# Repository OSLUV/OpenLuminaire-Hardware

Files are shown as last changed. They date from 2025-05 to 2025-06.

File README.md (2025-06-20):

# OpenLuminaire-Hardware
Electrical and mechanical files for OSLUV Luminaire - an [OSHWA certified](https://certification.oshwa.org/us002747.html) Open Source 222nm luminiare.

certification-mark-US002747-stacked

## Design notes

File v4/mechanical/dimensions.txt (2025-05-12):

"emitting_window_width"=63mm
"emitting_window_height"=48mm
"emitter_mounting_peg_diameter"=3.4mm
"emitter_wall_clearance"=0.5mm
"wall_thickness"=2mm
"ballast_pcb_length"=88.9mm
"ballast_pcb_width"=88.9mm
"ballast_pcb_clearance"=0.3mm
"emitter_balast_separation"=8mm
"emitter_ballast_spacer_clearance"=0.2mm
"edge_radius"=5mm
"grille_slot_width"=2mm
"grille_slot_length"=3.5mm
"grille_spacing"=6.3mm
"button_hole_diameter"=3.5mm
"hoop_inside_width"=75.9mm
"hoop_inside_height"=65mm
"hoop_inner_outer_clearance"=0.05mm

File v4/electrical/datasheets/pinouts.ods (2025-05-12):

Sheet: TPS54202_buck
Pin Number | Pin Name | Electrical Type | Group | Description
1 | GND | Power |  | Ground pin. Source terminal of low-side power NFET as well as the ground terminal for controller circuit. Connect sensitive VFB to this GND at a single point.
2 | SW | Power |  | Switch node connection between high-side NFET and low-side NFET.
3 | VIN | Power |  | Input voltage supply pin. The drain terminal of high-side power NFET
4 | FB | Input |  | Converter feedback input. Connect to output voltage with feedback resistor divider.
5 | EN | Input |  | This pin is the enable pin. Float the EN pin to enable.
6 | BOOT | Power |  | Supply input for the high-side NFET gate drive circuit. Connect a 0.1-μF capacitor between BOOT and SW pins.
Undervoltage Lockout
 |  | VSTART (V) | VSTOP (V) | VENfalling (V) | VENrising (V) | Ip (μA) | Ih (μA)
 |  | 22.2 | 20.185 | 1.19 | 1.22 | 0.7 | 1.55
R4 (Ω) | R5 (Ω)
937395.397489541 | 52856.9532713037
R4 Rounded (kΩ) | R5 Rounded (kΩ)
937 | 52.9

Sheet: Sheet2
Number | Name | Type | Description
1 | Vdd_IO | Power | Power supply for I/O pins
2 | NC | NC | Not connected
3 | NC | NC | Not connected
4 | SCL/SPC | Input | Clock
5 | GND | Power | 0V supply
6 | SDA/SDI/SDO | I/O | I2C Serial data/SPI data in/3-wire data out
7 | SDO/SA0 | I/O | SPI serial data output (SDO)/I2C address LSB
8 | CS | Input | Low: SPI enabled/ High: I2C enabled
9 | INT2 | Output | Inertial interrupt 2
10 | RES | Input | Connect to GND
11 | INT1 | Output | Inertial interrupt 1
12 | GND | Power | 0V supply
13 | ADC3 | Input | Analog-to-digital converter input 3
14 | Vdd | Power | Power supply
15 | ADC2 | Input | Analog-to-digital converter input 2
16 | ADC1 | Input | Analog-to-digital converter input 1

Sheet: STUSB4500_USB_PD
Pin Number | Pin Name | Electrical Type | Group | Description | Typical Connection
1 | CC1DB | Input |  | Dead battery enable on CC1 pin | To CC1 pin if used or ground
2 | CC1 | I/O |  | Type-C configuration channel 1 | To Type-C receptacle A5
3 | NC | Passive |  | Not Connected | Floating
4 | CC2 | I/O |  | Type-C configuration channel 2 | To Type-C receptacle B5
5 | CC2DB | I/O |  | Dead battery enable on CC2 pin | To CC2 pin if used or ground
6 | RESET | Input |  | Reset input, active high | From system
7 | SCL | I/O | I2C | I2C clock input | To I²C master, ext. pull-up
8 | SDA | I/O | I2C | I2C data input/output, active low open drain | To I²C master, ext. pull-up
9 | DISCH | I/O |  | Internal discharge path or external discharge path enable, active low open drain | From power system (internal path) or to the discharge path switch (external path), ext. pull- up
10 | GND | Power | Power | Ground | Ground
11 | ATTACH | Open Collector | Status | Attachment detection, active low open drain | To MCU if any, ext. pull-up
12 | ADDR0 | Input | I2C | I²C device address setting | Static, to ground or ext. pull-up for address selection, to ground if no connection to MCU
13 | ADDR1 | Input | I2C | I²C device address setting | Static, to ground or ext. pull-up for address selection, to ground if no connection to MCU
14 | POWER_OK3 | Open Collector | Status | Power contract flag, active low open drain | To power system, ext. pull-up
15 | GPIO | Open Collector | Status | General purpose output, active low open drain | To system, ext. pull-up
16 | VBUS_EN_SNK | Open Collector | Status | VBUS sink power path enable, active low open drain | To power switch or to power system, ext. pull-up
17 | A_B_SIDE | Open Collector | Status | Cable orientation, active low open drain | USB super speed MUX select, ext. pull-up
18 | VBUS_VS_DISCH | Input |  | VBUS voltage monitoring and discharge path | From VBUS, receptacle side
19 | ALERT | Open Collector | I2C | I2C interrupt, active low open drain | To I²C master, ext. pull-up
20 | POWER_OK2 | Open Collector | Status | Power contract flag, active low open drain | To power switch or to power system, ext. pull-up
21 | VREG_1V2 | Power | Power | 1.2 V internal regulator output | 1 µF typ. decoupling capacitor
22 | VSYS | Power | Power | Power supply from system | From power system, connect to ground if not used
23 | VREG_2V7 | Power | Power | 2.7 V internal regulator output | 1 µF typ. decoupling capacitor
24 | VDD | Power | Power | Power supply from USB power line | From VBUS, receptacle side
PAD | GND | Power | Power | Exposed pad is connected to ground | To ground

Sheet: TPS55340_Boost
Pin Number | Pin Name | Electrical Type | Group | Description
1 | SW | Power |  | SW is the drain of the internal power MOSFET. Connect SW to the switched side of the boost or SEPIC inductor or the flyback transformer.
2 | VIN | Power |  | The input supply pin to the IC. Connect VIN to a supply voltage between 2.9 V and 32 V. It is acceptable for the voltage on the pin to be different from the boost power stage input.
3 | EN | Input |  | Enable pin. When the voltage of this pin falls below the enable threshold for more than 1 ms, the IC turns off.
4 | SS | Input |  | Soft-start programming pin. A capacitor between the SS pin and AGND pin programs soft-start timing.
5 | SYNC | Input |  | Switching frequency synchronization pin. An external clock signal can be used to set the switching frequency between 200 kHz and 1.0 MHz. If not used, this pin should be tied to AGND.
6 | AGND | Power |  | Signal ground of the IC
7 | COMP | Output |  | Output of the transconductance error amplifier. An external RC network connected to this pin compensates the regulator feedback loop.
8 | FB | Input |  | Error amplifier input and feedback pin for positive voltage regulation. Connect to the center tap of a resistor divider to program the output voltage.
9 | FREQ | Input |  | Switching frequency program pin. An external resistor connected between the FREQ pin and AGND sets the switching frequency.
10 | NC | Power |  | Reserved pin that must be connected to ground
11 | PGND | Power |  | Power ground of the IC. It is connected to the source of the internal power MOSFET switch.
12 | PGND | Power |  | Power ground of the IC. It is connected to the source of the internal power MOSFET switch.
13 | PGND | Power |  | Power ground of the IC. It is connected to the source of the internal power MOSFET switch.
14 | NC | Power |  | Reserved pin that must be connected to ground
15 | SW | Power |  | SW is the drain of the internal power MOSFET. Connect SW to the switched side of the boost or SEPIC inductor or the flyback transformer.
16 | SW | Power |  | SW is the drain of the internal power MOSFET. Connect SW to the switched side of the boost or SEPIC inductor or the flyback transformer.
PAD | PowerPAD | Power |  | The PowerPAD should be soldered to the AGND. If possible, use thermal vias to connect to internal ground plane for improved power dissipation.

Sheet: ESP32-C3-WROOM-02-N4
Pin Number | Pin Name | Electrical Type | Group | Description
1 | 3V3 | Power | Power | Power supply
2 | EN | Input |  | High: on, enables the chip. Low: off, the chip powers off. Note: Do not leave the EN pin floating.
3 | GPIO4/ADC1_CH4/FSPIHD/MTMS | I/O | SPI | GPIO4, ADC1_CH4, FSPIHD, MTMS
4 | GPIO5/ADC2_CH0/FSPIWP/MTDI | I/O | SPI | GPIO5, ADC2_CH0, FSPIWP, MTDI
5 | GPIO6/FSPICLK/MTCK | I/O | SPI | GPIO6, FSPICLK, MTCK
6 | GPIO7/FSPID/MTDO | I/O | SPI | GPIO7, FSPID, MTDO
7 | GPIO8 | I/O | GPIO | GPIO8
8 | GPIO9 | I/O | GPIO | GPIO9
9 | GND | Power | Power | Ground
10 | GPIO10/FSPICS0 | I/O | GPIO | GPIO10, FSPICS0
11 | GPIO20/U0RXD | I/O | GPIO | GPIO20, U0RXD
12 | GPIO21/U0TXD | I/O | GPIO | GPIO21, U0TXD
13 | GPIO18/USB_D- | I/O | GPIO | GPIO18, USB_D-
14 | GPIO19/USB_D+ | I/O | GPIO | GPIO19, USB_D+
15 | GPIO3/ADC1_CH3 | I/O | GPIO | GPIO3, ADC1_CH3
16 | GPIO2/ADC1_CH2/FSPIQ | I/O | GPIO | GPIO2, ADC1_CH2, FSPIQ
17 | GPIO1/ADC1_CH1/XTAL_32K_N | I/O | GPIO | GPIO1, ADC1_CH1, XTAL_32K_N
18 | GPIO0/ADC1_CH0/XTAL_32K_P | I/O | GPIO | GPIO0, ADC1_CH0, XTAL_32K_P
19 | GND | Power | Power | Ground

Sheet: ESP32-C6-MINI-1-N4
Pin Number | Pin Name | Electrical Type | Group | Description | Function Names
1 | GND | Power | Power | Ground | GND
2 | GND | Power | Power | Ground | GND
3 | 3V3 | Power | Power | Power supply | 3V3
4 | NC | Passive | NC | NC | NC
5 | IO2 | I/O | GPIO | GPIO2, LP_GPIO2, LP_UART_RTSN, ADC1_CH2, FSPIQ | GPIO2/LP_GPIO2/LP_UART_RTSN/ADC1_CH2/FSPIQ
6 | IO3 | I/O | GPIO | GPIO3, LP_GPIO3, LP_UART_CTSN, ADC1_CH3 | GPIO3/LP_GPIO3/LP_UART_CTSN/ADC1_CH3
7 | NC | Passive | NC | NC | NC
8 | EN | Input |  | High: on, enables the chip. Low: off, the chip powers off. Note: Do not leave the EN pin floating. | EN
9 | IO4 | I/O | GPIO | MTMS, GPIO4, LP_GPIO4, LP_UART_RXD, ADC1_CH4, FSPIHD | MTMS/GPIO4/LP_GPIO4/LP_UART_RXD/ADC1_CH4/FSPIHD
10 | IO5 | I/O | GPIO | MTDI, GPIO5, LP_GPIO5, LP_UART_TXD, ADC1_CH5, FSPIWP | MTDI/GPIO5/LP_GPIO5/LP_UART_TXD/ADC1_CH5/FSPIWP
11 | GND | Power | Power | Ground | GND
12 | IO0 | I/O | GPIO | GPIO0, XTAL_32K_P, LP_GPIO0, LP_UART_DTRN, ADC1_CH0 | GPIO0/XTAL_32K_P/LP_GPIO0/LP_UART_DTRN/ADC1_CH0
13 | IO1 | I/O | GPIO | GPIO1, XTAL_32K_N, LP_GPIO1, LP_UART_DSRN, ADC1_CH1 | GPIO1/XTAL_32K_N/LP_GPIO1/LP_UART_DSRN/ADC1_CH1
14 | GND | Power | Power | Ground | GND
15 | IO6 | I/O | GPIO | MTCK, GPIO6, LP_GPIO6, LP_I2C_SDA, ADC1_CH6, FSPICLK | MTCK/GPIO6/LP_GPIO6/LP_I2C_SDA/ADC1_CH6/FSPICLK
16 | IO7 | I/O | GPIO | MTDO, GPIO7, LP_GPIO7, LP_I2C_SCL, FSPID | MTDO/GPIO7/LP_GPIO7/LP_I2C_SCL/FSPID
17 | IO12 | I/O | GPIO | GPIO12, USB_D- | GPIO12/USB_D-
18 | IO13 | I/O | GPIO | GPIO13, USB_D+ | GPIO13/USB_D+
19 | IO14 | I/O | GPIO | GPIO14 | GPIO14
20 | IO15 | I/O | GPIO | GPIO15 | GPIO15
21 | NC | Passive | NC | NC | NC
22 | IO8 | I/O | GPIO | GPIO8 | GPIO8
23 | IO9 | I/O | GPIO | GPIO9 | GPIO9
24 | IO18 | I/O | GPIO | GPIO18, SDIO_CMD, FSPICS2 | GPIO18/SDIO_CMD/FSPICS2
25 | IO19 | I/O | GPIO | GPIO19, SDIO_CLK, FSPICS3 | GPIO19/SDIO_CLK/FSPICS3
26 | IO20 | I/O | GPIO | GPIO20, SDIO_DATA0, FSPICS4 | GPIO20/SDIO_DATA0/FSPICS4
27 | IO21 | I/O | GPIO | GPIO21, SDIO_DATA1, FSPICS5 | GPIO21/SDIO_DATA1/FSPICS5
28 | IO22 | I/O | GPIO | GPIO22, SDIO_DATA2 | GPIO22/SDIO_DATA2
29 | IO23 | I/O | GPIO | GPIO23, SDIO_DATA3 | GPIO23/SDIO_DATA3
30 | RXD0 | I/O | GPIO | U0RXD, GPIO17, FSPICS1 | U0RXD/GPIO17/FSPICS1
31 | TXD0 | I/O | GPIO | U0TXD, GPIO16, FSPICS0 | U0TXD/GPIO16/FSPICS0
32 | NC | Passive | NC | NC | NC
33 | NC | Passive | NC | NC | NC
34 | NC | Passive | NC | NC | NC
35 | NC | Passive | NC | NC | NC
36 | GND | Power | Power | Ground | GND
37 | GND | Power | Power | Ground | GND
38 | GND | Power | Power | Ground | GND
39 | GND | Power | Power | Ground | GND
40 | GND | Power | Power | Ground | GND
41 | GND | Power | Power | Ground | GND
42 | GND | Power | Power | Ground | GND
43 | GND | Power | Power | Ground | GND
44 | GND | Power | Power | Ground | GND
45 | GND | Power | Power | Ground | GND
46 | GND | Power | Power | Ground | GND
47 | GND | Power | Power | Ground | GND
48 | GND | Power | Power | Ground | GND
49 | GND | Power | Power | Ground | GND
50 | GND | Power | Power | Ground | GND
51 | GND | Power | Power | Ground | GND
52 | GND | Power | Power | Ground | GND
53 | GND | Power | Power | Ground | GND

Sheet: TMAG5273_Hall
Pin Number | Pin Name | Electrical Type | Group | Description
1 | SCL | I/O | Data | Serial clock.
2 | GND | Power | Power | Ground
3 | GND_(TEST) | Input | Data | TI Test Pin. Connect to ground in application.
4 | VCC | Power | Power | Power supply (1.7V - 3.6V)
5 | \INT | I/O | Data | Interrupt input/ output. If not used and connected to ground, set MASK_INTB = 1b.
6 | SDA | I/O | Data | Serial data.

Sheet: ushio_pxz120i3_ballast_dimming
Dimming on Pin 3
Minimum Voltage (V) | Target Voltage (V) | Maximum Voltage (V) | Power Level (%) | Theoretical PWM Duty Cycle (%)
0 | 0 | 1 | 100 | 0
1 | 1.5 | 2 | 70 | 45
2 | 2.5 | 3 | 40 | 75
3 | 3.5 | 4 | 20 | 100

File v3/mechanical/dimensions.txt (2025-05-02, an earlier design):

"emitting_window_width"=63mm
"emitting_window_height"=48mm
"emitter_mounting_peg_diameter"=3.4mm
"wall_thickness"=2mm
"ballast_pcb_length"=88.9mm
"ballast_pcb_width"=88.9mm
"emitter_balast_separation"=5mm
"emitter_wall_clearance"=0.5mm
"ballast_pcb_clearance"=0.3mm
"emitter_ballast_spacer_clearance"=0.2mm

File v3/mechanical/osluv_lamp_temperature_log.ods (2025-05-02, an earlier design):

Fan disabled, 2024-03-18
Heatsink Temperature (°C) | Transformer Temperature (°C) | Time
25.5 | 25.6 | 17:21:00
25.5 | 25.5 | 17:21:01
25.5 | 25.5 | 17:21:01
25.5 | 25.5 | 17:21:02
25.5 | 25.5 | 17:21:02
25.5 | 25.5 | 17:21:03
25.5 | 25.5 | 17:21:04
25.5 | 25.5 | 17:21:04
25.5 | 25.5 | 17:21:05
25.5 | 25.5 | 17:21:05
25.5 | 25.5 | 17:21:06
25.5 | 25.5 | 17:21:07
25.5 | 25.6 | 17:21:07
25.3 | 30.7 | 17:21:08
25.3 | 31.2 | 17:21:08
25.3 | 31.5 | 17:21:09
25.3 | 31.8 | 17:21:10
25.4 | 31.9 | 17:21:10
25.4 | 32.1 | 17:21:11
25.4 | 32.2 | 17:21:12
25.4 | 32.3 | 17:21:12
25.4 | 32.4 | 17:21:13
25.4 | 32.4 | 17:21:13
25.4 | 32.7 | 17:21:14
25.4 | 32.8 | 17:21:15
25.4 | 32.9 | 17:21:15
25.5 | 33.0 | 17:21:16
25.5 | 33.1 | 17:21:16
25.5 | 33.1 | 17:21:17
25.6 | 33.2 | 17:21:18
25.6 | 33.2 | 17:21:18
25.6 | 33.3 | 17:21:19
25.7 | 33.2 | 17:21:19
25.7 | 33.2 | 17:21:20
25.8 | 33.1 | 17:21:21
25.8 | 33.0 | 17:21:21
25.9 | 32.9 | 17:21:22
26.0 | 32.8 | 17:21:22
26.0 | 32.7 | 17:21:23
26.1 | 32.7 | 17:21:24
26.1 | 32.6 | 17:21:24
26.2 | 32.5 | 17:21:25
26.2 | 32.5 | 17:21:25
26.3 | 32.5 | 17:21:26
26.3 | 32.6 | 17:21:27
26.4 | 32.6 | 17:21:27
26.4 | 32.7 | 17:21:28
26.4 | 32.7 | 17:21:28
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

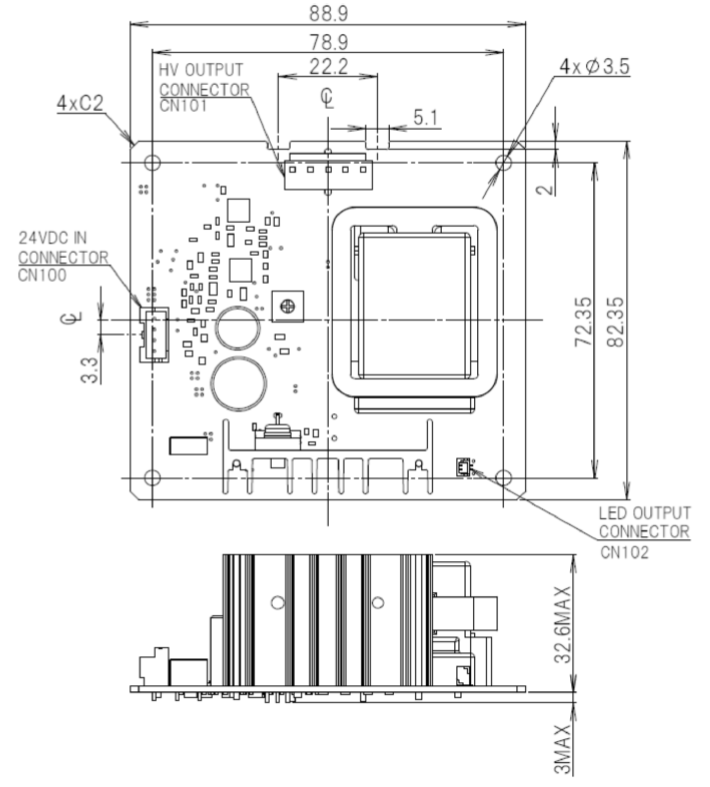
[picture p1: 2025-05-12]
v4/electrical/datasheets/ushio_pxz120i2_ballast_dimensions.png

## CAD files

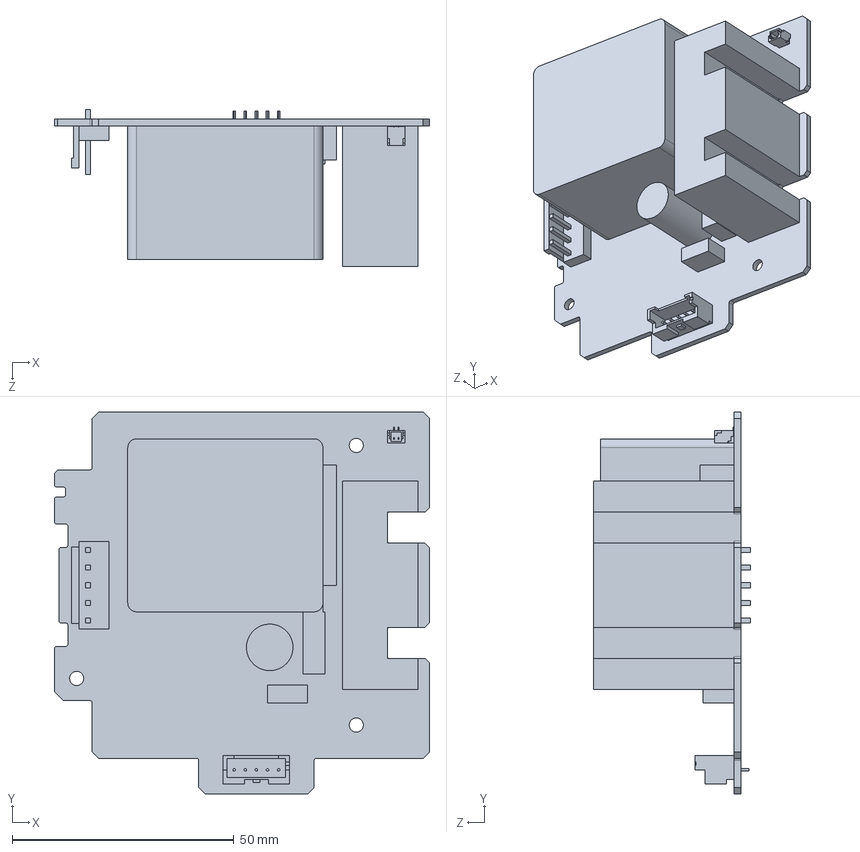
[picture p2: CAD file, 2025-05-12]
v4/mechanical/ushio_pxz120i3_ballast_assembly.sldprt
84.5 x 86.0 x 35.3 mm

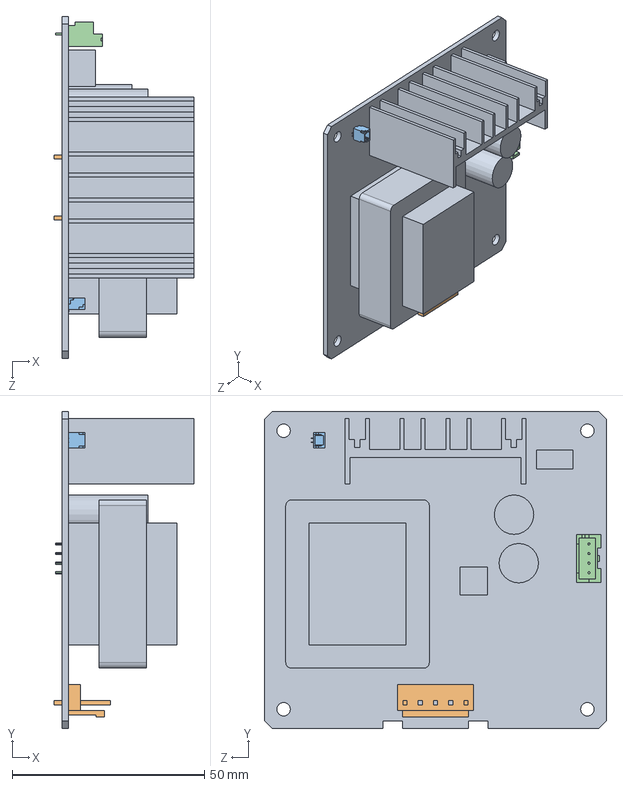
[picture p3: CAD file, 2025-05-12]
v4/mechanical/ushio_pxz120i2_ballast.sldasm
36.3 x 82.3 x 88.9 mm
ushio_pxz120i2_ballast
b5p-vh_jst_vh_connector
bm02b-srss-tb_jst_sh_connector.step
b04b-xask-1_connector

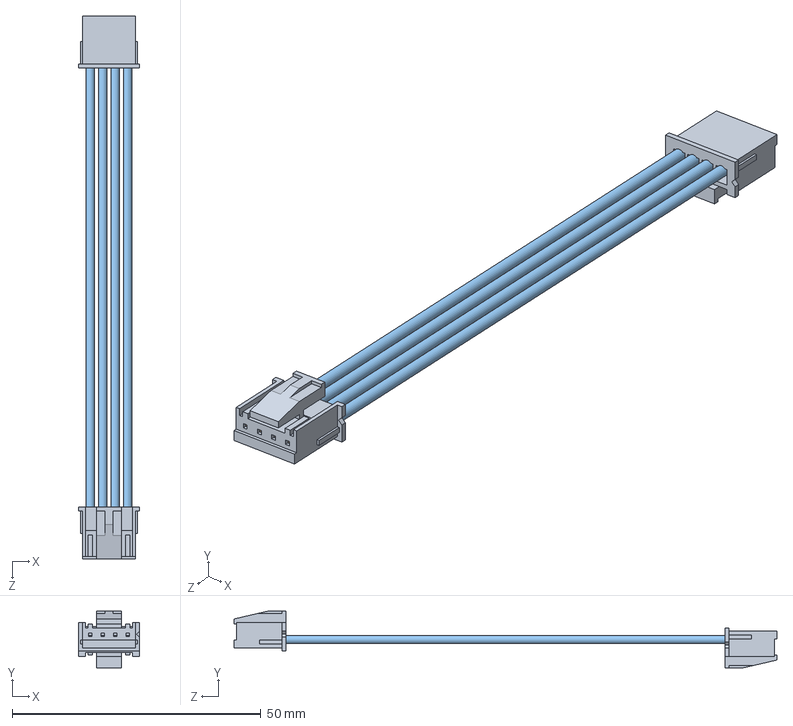
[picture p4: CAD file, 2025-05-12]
v4/electrical/cables/4-pin_ballast_cable.sldasm
12.3 x 11.5 x 109.2 mm
xarp-04v_xa_housing x 2
sxa-001t-p0.6_xa_contact.step x 8
jumper_wire x 4

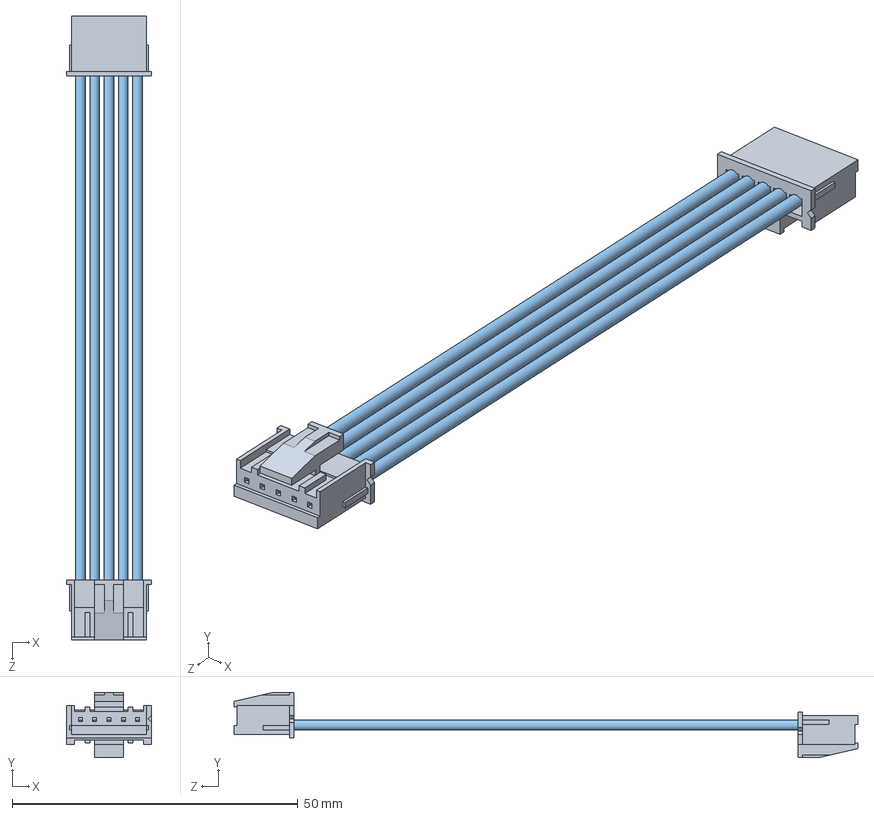
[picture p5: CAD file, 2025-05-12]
v4/electrical/cables/5-pin_ballast_cable.sldasm
14.8 x 11.5 x 109.2 mm
xarp-05v_xa_housing x 2
sxa-001t-p0.6_xa_contact.step x 10
jumper_wire x 5

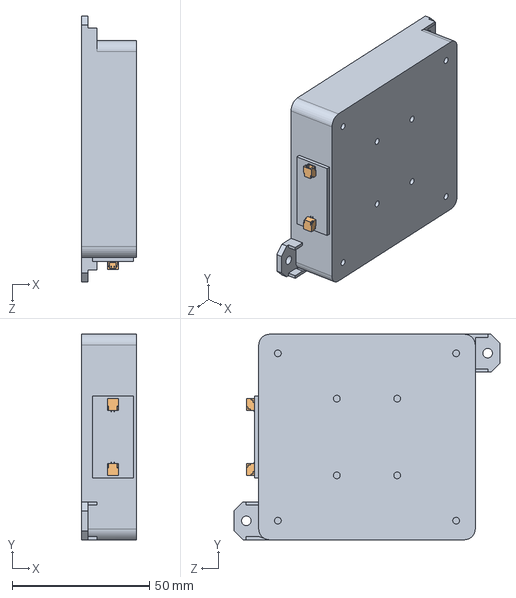
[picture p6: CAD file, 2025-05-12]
v4/mechanical/ushio_care222_emitter.sldasm
20.2 x 75.0 x 97.0 mm
ushio_care222_emitter
sm02b-srss-tb_jst_sh_connector x 2

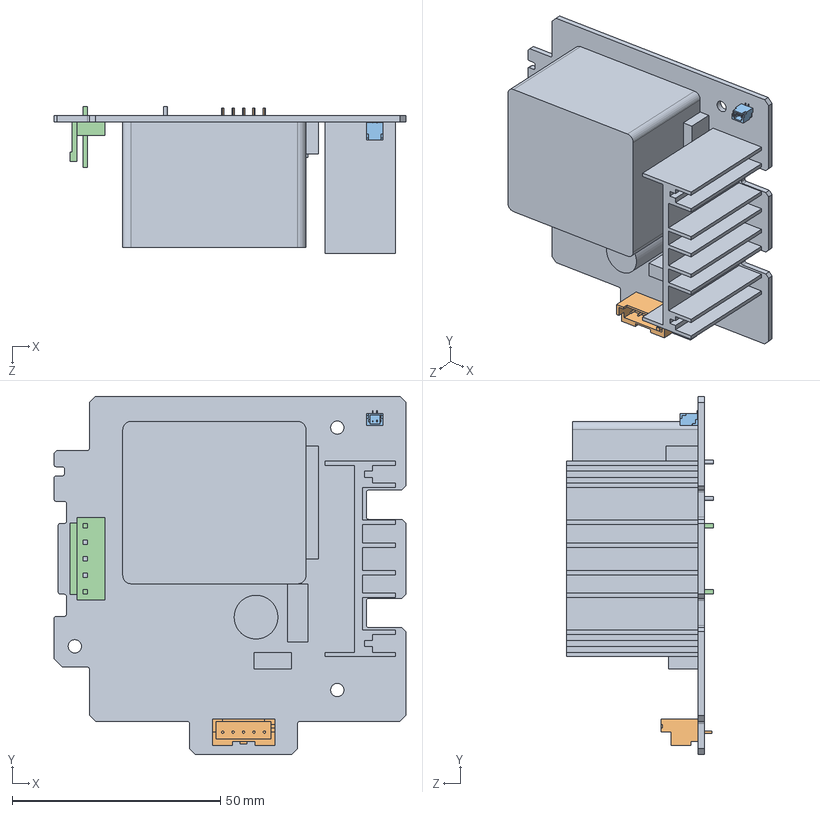
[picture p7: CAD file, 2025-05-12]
v4/mechanical/ushio_pxz120i3_ballast.sldasm
84.5 x 86.0 x 35.4 mm
ushio_pxz120i3_ballast
b05b-xask-1_connector.step
bm02b-srss-tb_jst_sh_connector.step
b5p-vh_jst_vh_connector

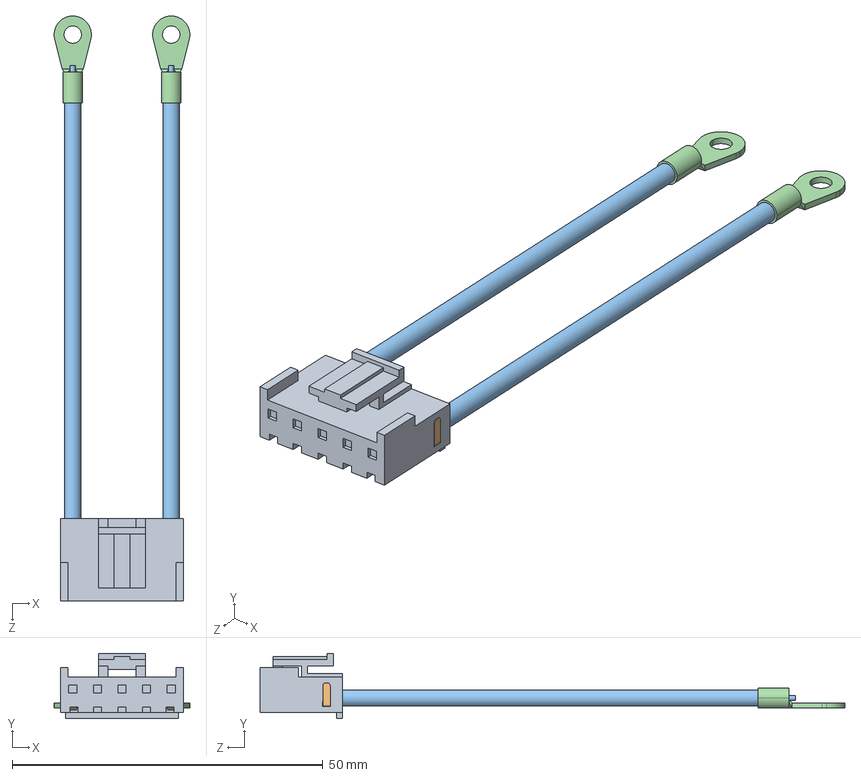
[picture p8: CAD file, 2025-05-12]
v4/electrical/cables/hv_cable.sldasm
21.8 x 10.5 x 94.1 mm
vhr-5n_jst_xh_housing
svh-21t-p1.1_jst_xh_contact.step x 2
hv_wire x 2
3240069_m2.5_ring_terminal.step x 2

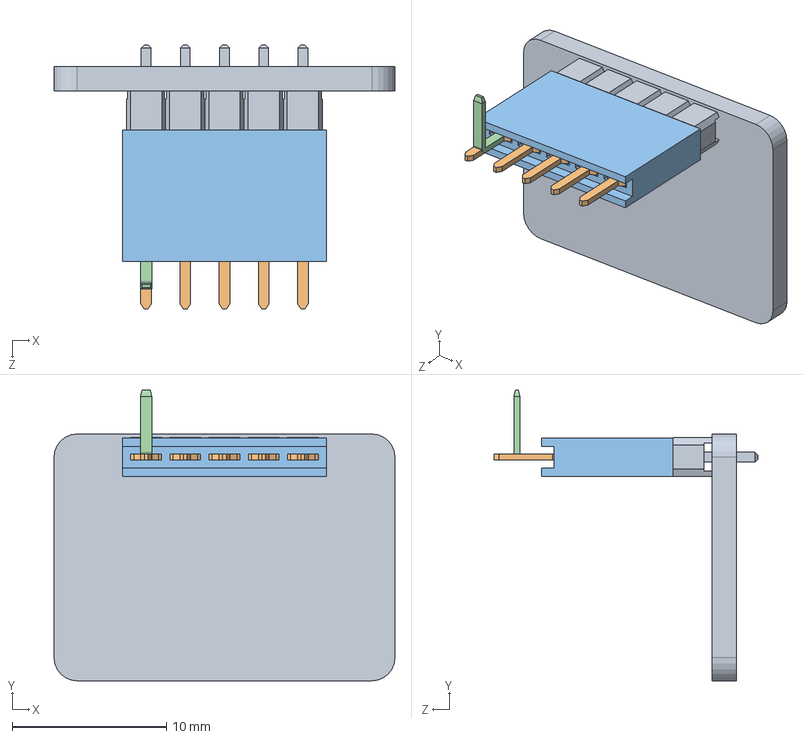
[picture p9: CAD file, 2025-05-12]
v4/electrical/models/radar.sldasm
22.1 x 18.8 x 17.1 mm
hlk-ld2410c_radar
6130xx11821_PIN.step x 5
61300511821.step

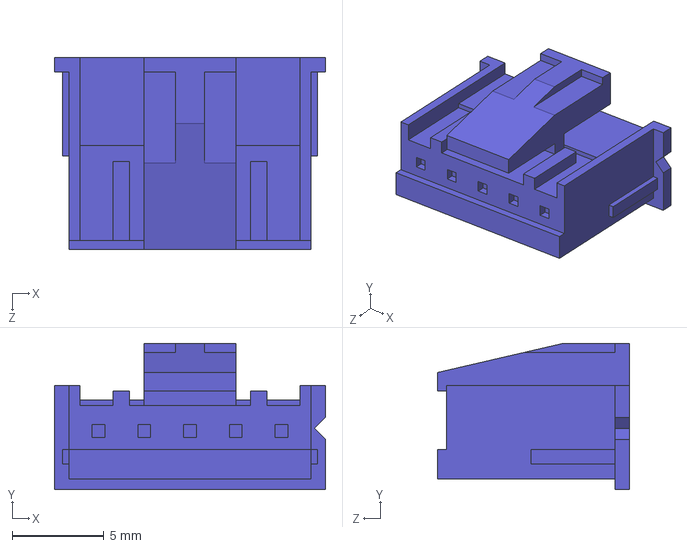
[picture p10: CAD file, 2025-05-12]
v4/electrical/cables/xarp-05v_xa_housing.step
14.8 x 8.00 x 10.5 mm

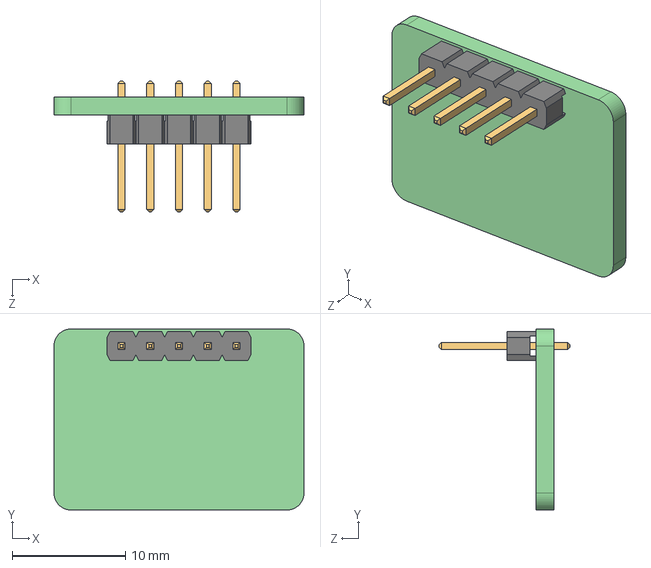
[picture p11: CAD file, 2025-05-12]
v4/electrical/models/hlk-ld2410c_radar.step
22.1 x 16.0 x 11.5 mm

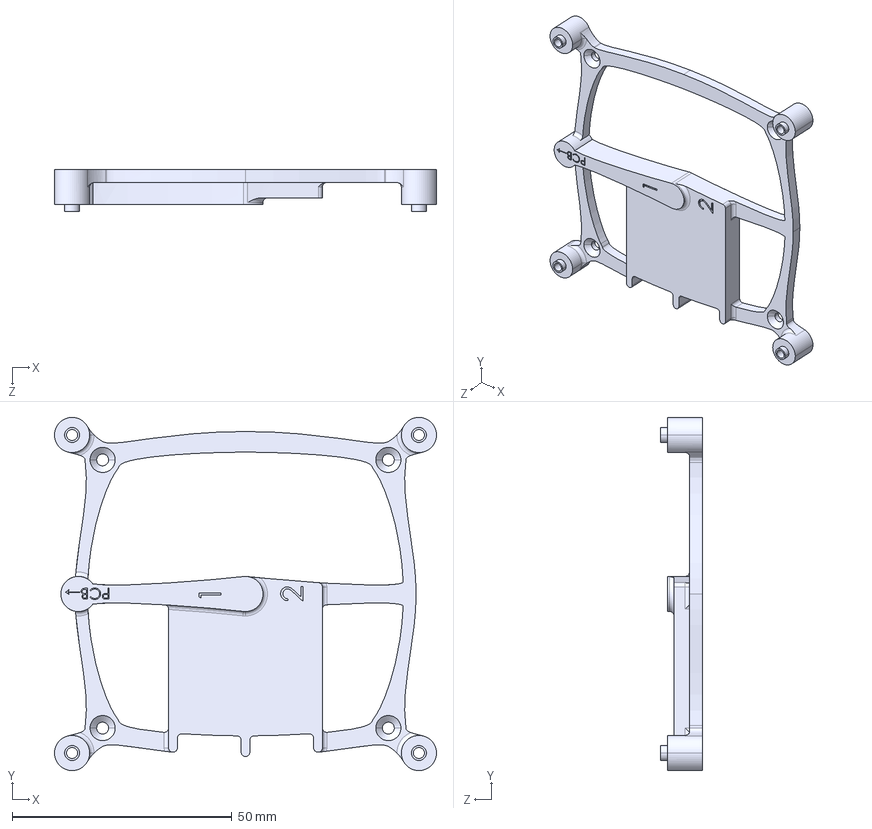
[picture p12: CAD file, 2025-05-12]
v4/mechanical/printable_files/emitter_pxz120i2_ballast_spacer.step
86.9 x 80.4 x 9.60 mm

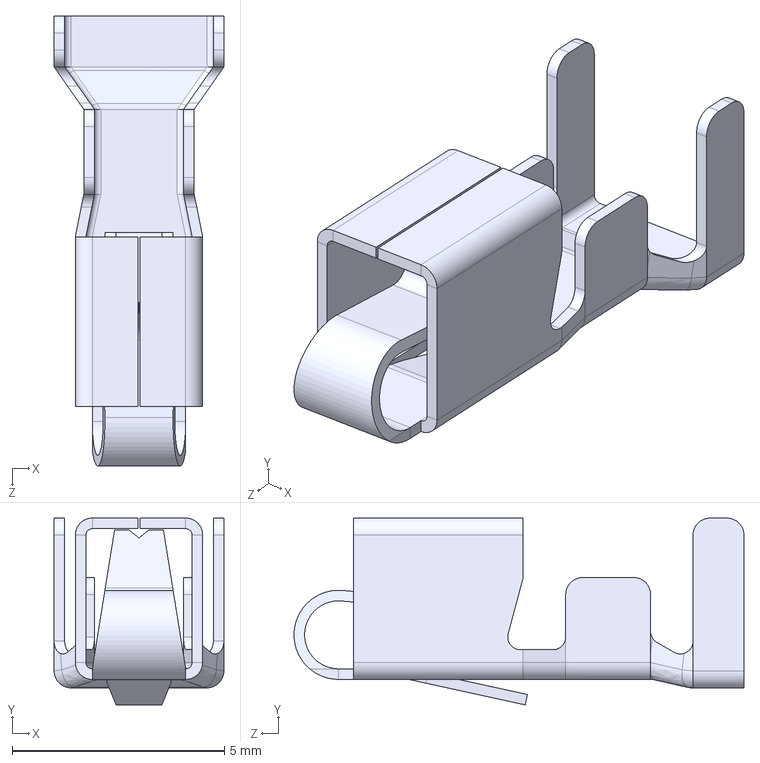
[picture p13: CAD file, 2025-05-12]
v4/electrical/cables/svh-21t-p1.1_xh_contact.step
4.00 x 4.40 x 10.6 mm

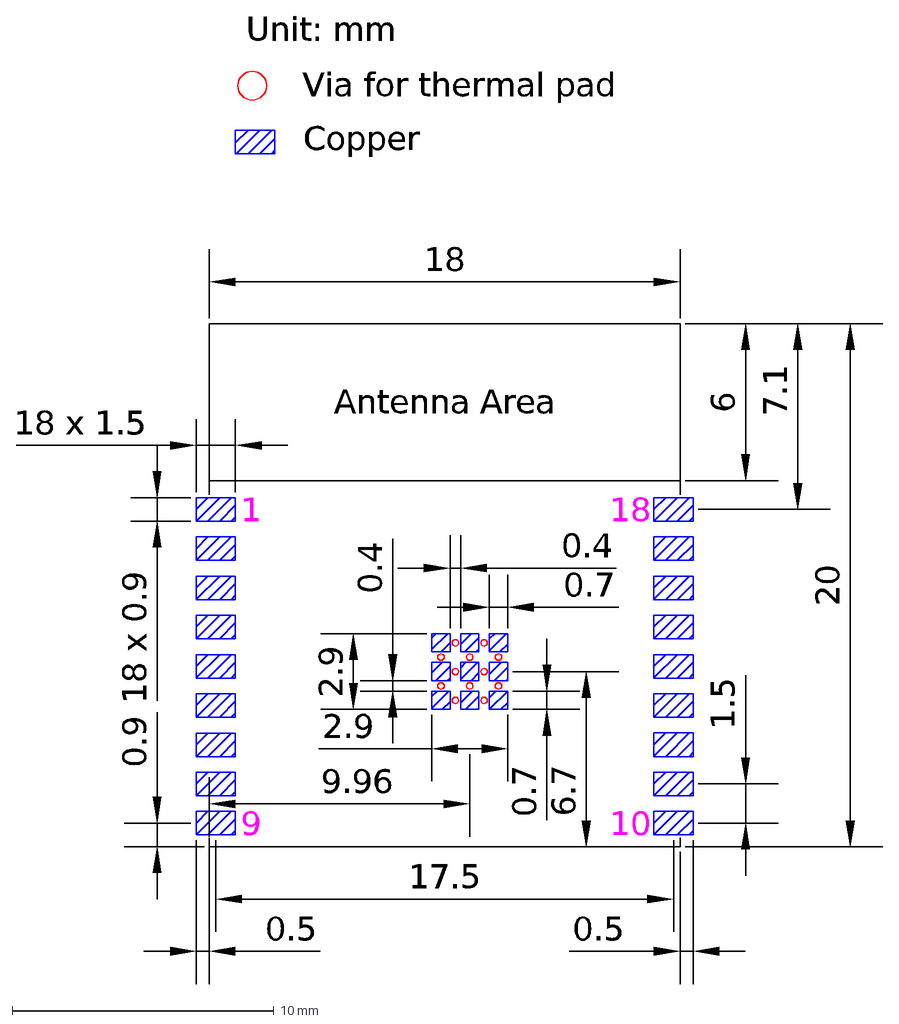
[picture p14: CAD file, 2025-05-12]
v4/electrical/datasheets/esp32-c3-wroom-02_wifi_bluetooth_module.dxf
Unit: mm
Copper
Via for thermal pad
1
9
18
10
Antenna Area
6
20
1.5
18 x 1.5
18 x 0.9
0.9
0.5
2.9
0.7
0.4
6.7
9.96
17.5
7.1

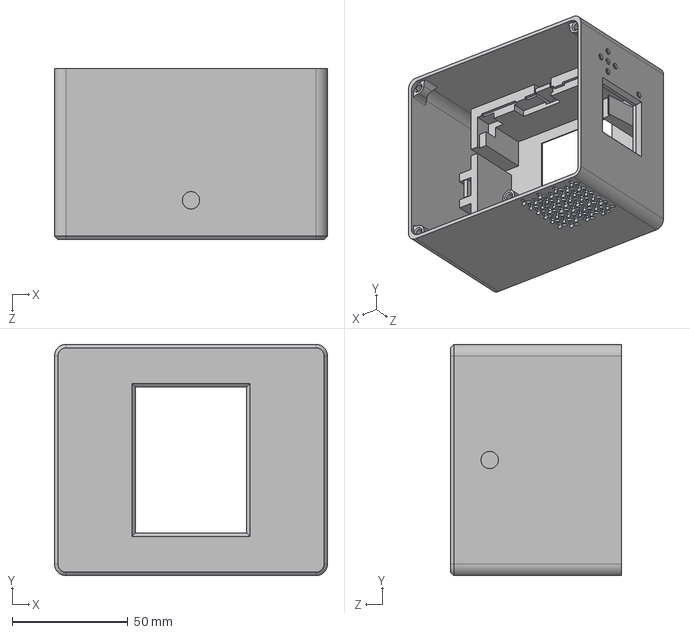
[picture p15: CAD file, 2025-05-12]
v4/mechanical/printable_files/housing.step
118.0 x 100.0 x 74.0 mm

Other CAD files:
v4/electrical/datasheets/fh35-15s-0.3shw(50)_connector.sldprt
v4/electrical/cables/xarp-04v_xa_housing.step
v4/electrical/models/fh35-15s-0.3shw(50)_connector.step
v4/mechanical/printable_files/emitter_pxz120i3_ballast_spacer.step
v3/electrical/models/2834006-2_wire_connector.step
v3/electrical/models/68016-105hlf.step
v3/electrical/models/dc0053_connector.sldprt
v3/electrical/models/dc0053_connector.step
v3/electrical/models/s04b-xask-1.step
v3/mechanical/back_plate.sldprt
v3/mechanical/cfm-4020cf-235-114_fan.sldprt
v3/mechanical/emitter_ballast_spacer.sldprt
v3/mechanical/hardware/47065t905_t-slot_nut.sldprt
v3/mechanical/hardware/94180a321_m2.5_threaded_insert.sldprt
v3/mechanical/hardware/99461a939_m3x6mm_self-tapping_screw.sldprt
v3/mechanical/hlk-ld2410c_radar.sldprt
v3/mechanical/housing.sldprt
v3/mechanical/lens_cap.sldprt
v3/mechanical/osluv_lamp.sldasm
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

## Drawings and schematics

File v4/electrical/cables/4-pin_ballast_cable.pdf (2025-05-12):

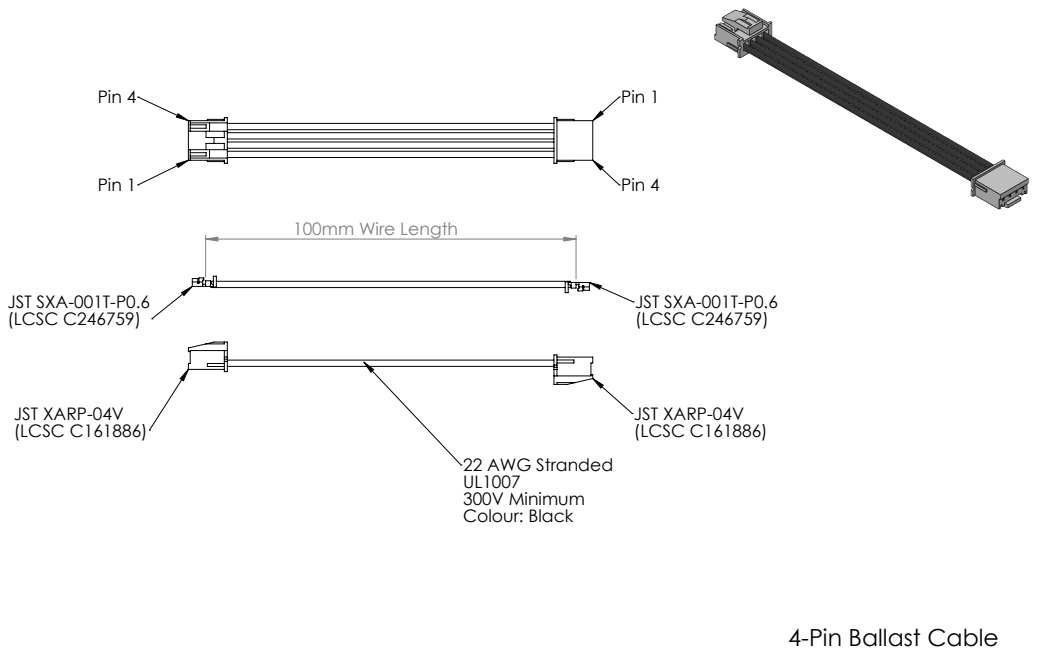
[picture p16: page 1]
JST XARP-04V (LCSC C161886); 22 AWG Stranded 300V Minimum Colour: Black; Pin 4; Pin 1; 100mm Wire Length; JST SXA-001T-P0.6 (LCSC C246759)

4-Pin Ballast Cable

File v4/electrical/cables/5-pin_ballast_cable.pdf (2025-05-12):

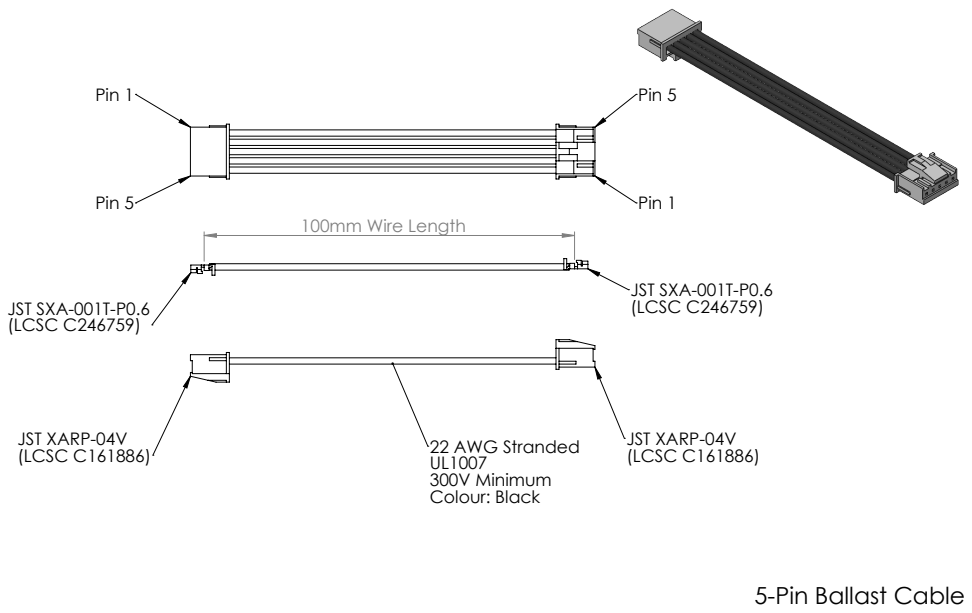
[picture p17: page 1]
JST XARP-04V (LCSC C161886); JST XARP-04V; Pin 1; Pin 5; 100mm Wire Length; JST SXA-001T-P0.6 (LCSC C246759)

(LCSC C161886) 22 AWG Stranded
300V Minimum
Colour: Black

5-Pin Ballast Cable

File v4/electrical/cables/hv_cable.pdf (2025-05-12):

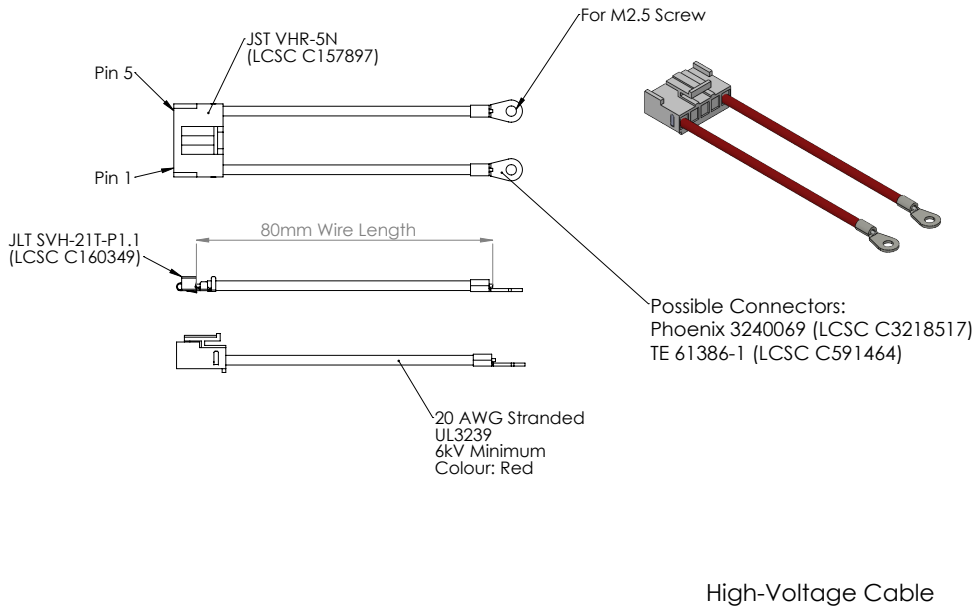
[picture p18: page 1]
JLT SVH-21T-P1.1 (LCSC C160349); 80mm Wire Length; Pin 5; Pin 1; JST VHR-5N (LCSC C157897); Possible Connectors: Phoenix 3240069 (LCSC C3218517) TE 61386-1 (LCSC C591464); For M2.5 Screw; 20 AWG Stranded 6kV Minimum Colour: Red

High-Voltage Cable

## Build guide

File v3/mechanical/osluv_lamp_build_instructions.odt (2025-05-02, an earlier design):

OSLUV Lamp Build Instructions

# Printing Housing Parts

1. If you already have the 3D printed housing parts, skip this step.
2. The source files for the housing parts are in 3 separate files:
  a. housing.sldprt
  b. back_plate.sldprt
  c. emitter_ballast_spacer.sldprt
  d. shims.sldprt
  e. lens_cap.sldprt
3. Derived STEP files are also available:
  a. housing.step
  b. back_plate.step
  c. emitter_ballast_spacer.step
  d. shims.step
  e. lens_cap.step

# Housing Preparation

1. Remove all external burrs from 3D printed housing parts (black). Use a knife, chisel, and sandpaper as needed. Do not leave sharp edges.
2. Use a soldering iron to heat-press the M2.5 brass threaded inserts (4 per housing). Ensure they remain straight.
3. Slide the two 1/4”-20 threaded steel T-slot nuts into place.
4. Insert the two white plastic shims to prevent the T-slot nuts from falling out.

# Controller Preparation

1. Ensure resistors R1, R3, R5, and R6 are removed from the USHIO RP2040 Controller 1.0.
2. Unclip the fan wires from the fan housing, taking care not to stress the solder joint.
3. Cut the fan wires to a length of approximately 70mm.
4. Strip 8mm of insulation off the ends of the fan wires.
  1. Set the Knipex automatic stripper to “8mm”.
  2. Twist the strands together.
5. Tin the bare ends of the fan wires with solder.
6. Clean any flux off the tinned fan wires.
7. Insert the fan wires into the J3 connector.
  1. Match the red wire with “+”, and the black wire with “-”.
  2. Note: the wires are not removable. Please do not screw up.

# Controller Cable Preparation

1. Plug four 6” JST XA jumper wires into a 4-pin JST XA housing.
2. Connect the jumper wire in the pin 1 housing position to pin 1 of a second housing.
3. Continue connecting the remaining jumper wires to the second housing. Pin 2 to pin 2, pin 3 to pin 3, pin 4 to pin 4.

# High Voltage Cable Preparation

1. Cut two pieces of the white high-voltage silicone wire to a length of 80mm.
2. Strip 6mm of insulation off one end of each wire.
  1. Set the Knipex automatic stripper to “6mm”.
  2. Do NOT twist the strands together.
3. Crimp the M2.5 ring terminal on each wire, using the “22-14” slot.
4. Strip 3mm of insulation off the other end of each wire.
  1. Do NOT twist the strands together.
5. Crimp the JST VH terminal on each wire, uting the “20 AWG” slot.
6. Insert the JST VH terminals into the white JST VH housing. Use the two outermost slots.

# Emitter/Ballast Preparation

1. Place the emitter flat on a clean table, lens side down, with the green circuit board to your left.
2. Remove any screws from the “1” and “2” electrode terminals.
3. Connect the high voltage cable to the “1” and “2” electrode terminals.
  1. Use the two terminals closest to you.
  2. The high voltage cable should stick out towards you.
  3. Use the M2.5 x 8mm screws with captive lockwashers.
  4. Use a #1 phillips screwdriver, and torque the screws by hand to prevent damage.
4. Place the white emitter-ballast spacer on top of the emitter. The flat shield should cover the high voltage cables.
5. Screw the spacer in place with four black M2.5 flat head screws.
  1. Use a #1 phillips screwdriver, and the #3 torque setting on the Hitachi electric screwdriver.
6. Place the ballast on top of the spacer, with the CN101 high voltage connector closest to you.
7. Screw the ballast in place using four M3 self-tapping screws.
  1. Use a #1 phillips screwdriver, and the #3 torque setting on the Hitachi electric screwdriver.
8. Plug the high voltage cable onto connector CN101 of the ballast.
9. Connect the LED ignition cable.
  1. One end in CN102 of the ballast.
  2. The other end in CN1 of the emitter circuit board.

# Back Plate Preparation

1. Snap the fan into the housing back plate.
  1. Ensure the direction of airflow is inward.
  2. The wires should exit near the large flat surface of the back plate.
2. Insert the USHIO RP2040 Controller 1.0 power jack into the back place, ensuring the PCB is flush against the mounting pegs.
3. Screw the USHIO RP2040 Controller 1.0 in place using M3 self-tapping screws.
  1. Use a #1 phillips screwdriver, and the #3 torque setting on the Hitachi electric screwdriver.
4. Plug the radar PCB into the USHIO RP2040 Controller 1.0.
  1. Use a 5-pin jumper cable.
  2. Ensure the “TX” pin of the radar PCB matches up with the “TX” pin of the USHIO RP2040 Controller 1.0.
5. Plug the 4-pin JST XA cable into J2 of the USHIO RP2040 Controller 1.0.

# Housing Assembly

1. Place the housing flat on a clean table, emitter side down, with the fan grille facing you.
2. Lower the emitter-ballast assembly into the housing, with the high voltage cable facing you.
  1. The ballast PCB should be flush with the black plastic ledge of the housing.
  2. The high voltage cable should fit loosely, with black plastic of the housing on either side.
3. Place the radar PCB to the right side and slightly under the ballast PCB.
  1. Note, it will be secured in place by the back plate.
4. Plug in the 4-pin JST XA cable into CN100 of the ballast.
5. Carefully place the back plate onto the housing.
  1. This will require fiddling with the cables to ensure everything fits into place. Take your time, and beware of pinched cables.
6. Screw the back plate to the housing using four black M2.5 flat head screws.
  1. Use a #1 phillips screwdriver, and the #3 torque setting on the Hitachi electric screwdriver.

# Testing

1. Plug a 24V power supply into the power connector.
2. Turn on the cable’s power switch (if present).
3. Ensure the fan spins.
4. Ensure the UV lamp glows.

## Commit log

2025-05-02 Added design files.
    [2834006-2_wire_connector.step, 47065t905_t-slot_nut.sldprt, 68016-105hlf.step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]
2025-05-12 Organizing files.
    [22232021_0.1_header.step, 2834006-2_wire_connector.step, 3240069_m2.5_ring_terminal.step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]
2025-05-23 Revised V4 PCB.
    [91595a029_2mmx12mm_dowel_pin.sldprt, 91595a112_3mmx12mm_dowel_pin.sldprt, cylinder_magnet.sldprt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]
